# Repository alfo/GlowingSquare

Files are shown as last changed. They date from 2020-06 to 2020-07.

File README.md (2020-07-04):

# Glowing Square

This project is a purpose-built display based on a 64x32 LED matrix and an ESP32. The code can be easily adapted for other purposes, and includes code to fetch web requests, store config, etc.

I have made three displays so far: one that shows the current London Tube departures for my local station with data from TfL, one that shows planes flying over my house with data from Flightradar24 based on [this project](https://github.com/GroundBreakingItem0/esp8266_plane_tracker), and one that shows network statistics for my Unifi-based home network.



Full photo album [here](https://imgur.com/a/xTvUx8F).

## Features

* Fetches JSON data from an API at a given interval
* Parses the JSON and displays it
* Brightness controlled by MQTT
* "Party Mode" / Screensaver mode, turned on and off by MQTT
* WiFiManager-based hotspot for configuration

## Hardware Required
* 64x32 P4 LED Matrix (from [here](https://www.aliexpress.com/store/group/P4-led-module/1848738_509034839.html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))
* D1 Mini 32 (any of [these](https://www.aliexpress.com/wholesale?catId=0&initiative_id=SB_20200704011236&SearchText=mini+esp32))
* Optional: Brian Lough's Shield PCB (you can wire it yourself instead, but these are much neater) (from [here](https://www.tindie.com/products/brianlough/esp32-matrix-shield-mini-32/))
* 24V PSU (up to 35W per display) (I picked [this one](https://www.ebay.co.uk/itm/DC-5V-12V-24V-Universal-Regulated-Switching-Power-Supply-for-LED-Strip-CCTV-UK/162562112782) for 3 displays) 
* LM2596 Buck Converter to step down to 5V (from [here](https://www.aliexpress.com/wholesale?catId=0&initiative_id=SB_20200704011644&SearchText=LM2596))
* Two-core cable, Wago connectors/screw connectors, etc.
* 6x M3 12mm bolts, 16x 3mm short countersunk screws

You can just use a 5V power supply instead, but 100W+ ones tend to have loud fans in them, which is annoying, whereas my 24V 120W PSU is completely silent. It also helps with voltage drop if you're using long cables.

## Enclosure

See the files in the Enclosure folder for the STLs of the two 3D-printed parts of this project, as well as the full Fusion 360 model showing you how it all fits together and what wood is required for the project.

Back view

## Global Config Options

These options are available across all three displays:

* Hostname - what your device will show up in your router admin console as (can't contain spaces, etc)
* MQTT Server - the IP or domain name of your MQTT server
* MQTT Port - defaults to 1833
* MQTT Username
* MQTT Password

## MQTT Control

Set the room name (in the format `living_room` for example) in the web config interface, along with your MQTT server and port, etc. This will become the base of the topic when combined with the `MQTT_NAME` of your device in `mqtt.h`. Then the device will:

* Publish on `room_name/MQTT_NAME/mqtt` `connected` or `disconnected` as a last will and testament
* Listen on `room_name/MQTT_NAME/in` for messages in JSON format (e.g. `{ "brightness": 160 }` and will fade to the new brightness
* Listen on `room_name/state` for messages in JSON format (e.g. `{ "party_mode": "chill" }` (or `off` or `on`)

## Tube / London Bus

Find your TfL Stop ID [here](https://api.tfl.gov.uk/swagger/ui/index.html?url=/swagger/docs/v1#!/StopPoint/StopPoint_Search). TfL treats tube stops and bus stops the same, so if you provide the correct route and stop ID, it will work for both.

Config Options:

* TfL Stop ID
* TfL Route (e.g. `northern`, `circle`, `H91`, `9`), you can test your route [here](https://api.tfl.gov.uk/swagger/ui/index.html?url=/swagger/docs/v1#!/Line/Line_Arrivals)
* Direction (options are `outbound`, `inbound`, or empty for both)

## Flights

Use Google Maps or similar to find the longitude and latitude of the top left and bottom right points that define the area you want to monitor flights inside.

Config Options: 

* Flight Area in the format `51.5672,51.4131,-0.4146,0.1107` (for example)

## Unifi

Unlike the other two, this one requires a PHP script running on a web server (because Unifi needs 3 different API requests to fetch the info I wanted to display, and also Unifi returns JSON payloads that are too big to fit in the RAM of the ESP32).

Install the `GlowingSquare/Unifi/web/` files on your PHP server, and rename the `config.example.php` to `config.php`, filling in the necessary details as outlined by the code comments. Test that your server is working by visiting it in a web browser with `?width=64` appended to the URL to check you can scrape data correctly.

Config Options:

* Script URL as set up above, e.g. `http://10.0.1.9/glowingsquare/?width=64`

## Other Notes

This project was just started as a passtime during the 2020 COVID-19 lockdown as a bit of fun, happy to take questions but this isn't a long-term open source kinda deal, I'm just open-sourcing an already completed thing.

People have asked me if I'll be selling these, and I'll consider it and come up with a rough price estimate. It's a lot easier if you don't bother with the nice enclosure, which takes roughly 30% of the cost.

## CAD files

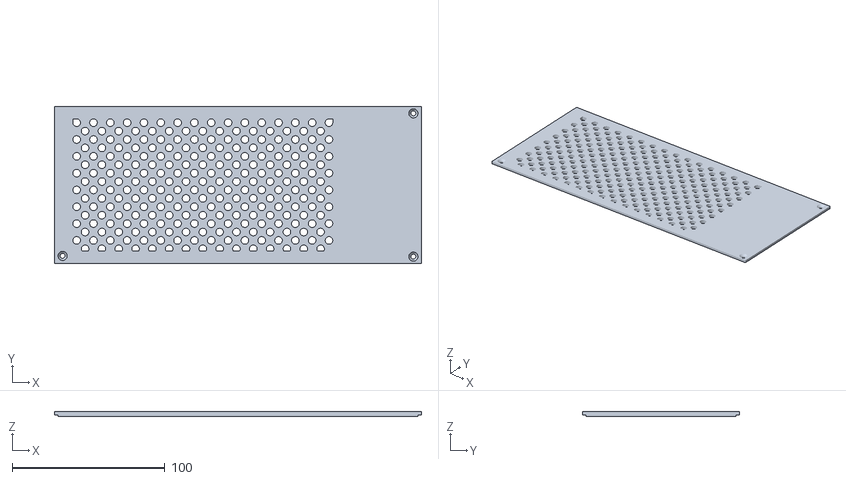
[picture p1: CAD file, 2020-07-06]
Enclosure/PSU Lid.stl
240.0 x 102.5 x 3.00

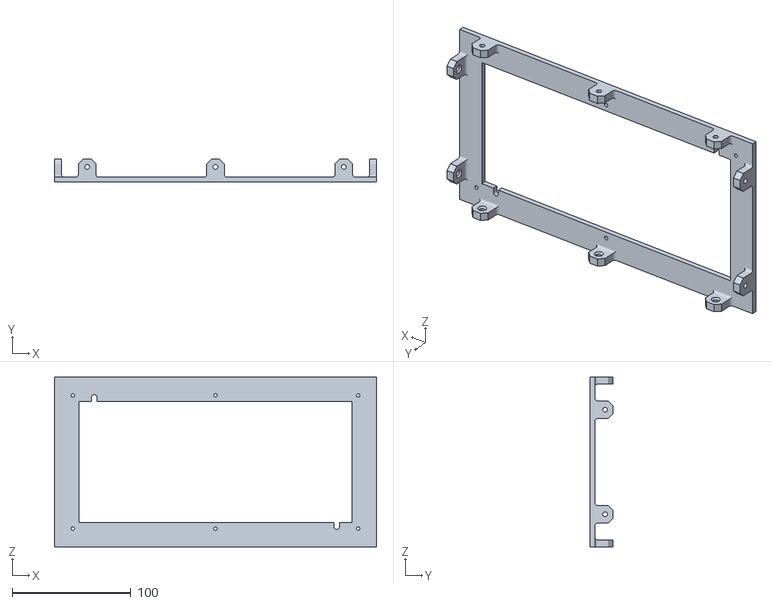
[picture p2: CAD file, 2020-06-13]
GlowingSquare_Tube/Enclosure/Display Mount.stl
271.0 x 19.0 x 143.0

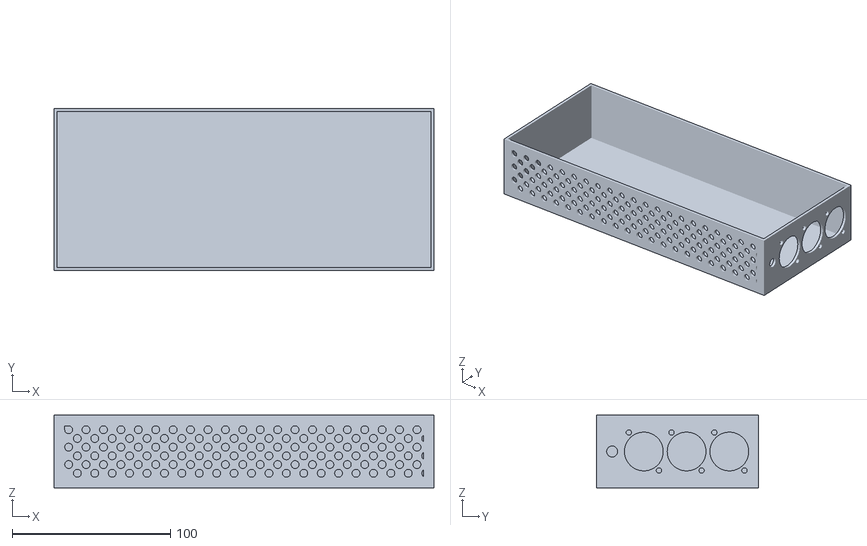
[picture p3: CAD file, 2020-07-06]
Enclosure/PSU Box.stl
240.0 x 102.5 x 46.0

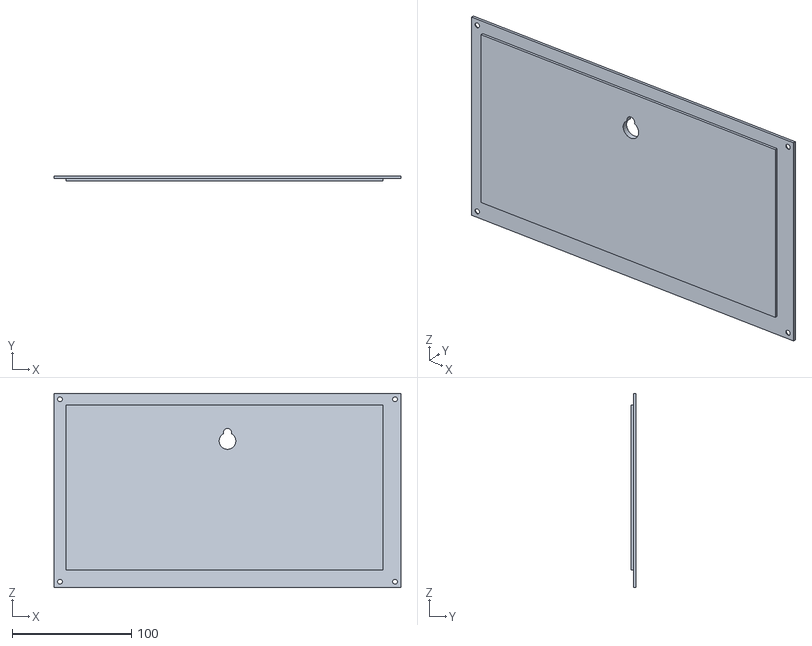
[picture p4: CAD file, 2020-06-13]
GlowingSquare_Tube/Enclosure/Wall Mount.stl
291.0 x 4.00 x 163.0

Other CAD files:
Enclosure/Wall Mount.stl
Enclosure/Glowing Square.f3d
GlowingSquare_Tube/Enclosure/Glowing Square.f3d

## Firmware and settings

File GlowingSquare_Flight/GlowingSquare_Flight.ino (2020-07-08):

/*
 *
 *
 *         _             ______
     /\   | |           |  ____|
    /  \  | | _____  __ | |__ ___  _ __ ___ _   _
   / /\ \ | |/ _ \ \/ / |  __/ _ \| '__/ _ \ | | |
  / ____ \| |  __/>  <  | | | (_) | | |  __/ |_| |
 /_/    \_\_|\___/_/\_\ |_|  \___/|_|  \___|\__, |
                                             __/ |
 Glowing Square: Flight Display             |___/
 For ESP32
 GlowingSquare_Flight.ino
 *
 */

// Include Libraries
#include <FS.h>            // this needs to be first, or it all crashes and burns...
#include <WiFiManager.h>   // https://github.com/tzapu/WiFiManager ~v2.0.0
#include <ArduinoJson.h>   // https://github.com/bblanchon/ArduinoJson ~v6.x.x
#include <PubSubClient.h>  // https://github.com/knolleary/pubsubclient ~v2.7.0
#include <ArduinoOTA.h>    // Included with core
#include <HTTPClient.h>    // To fetch data
                           // PxMatrix is included from inside the display.h file
#include <FastLED.h>       // For the animations during party mode

#ifdef ESP32
  #include <SPIFFS.h>
#endif

// Uncomment to reset device memory (useful to fix corruption / force new settings)
//#define START_ANEW

int party_mode = 0; // 0 = off, 1 = chill, 2 = party
int last_party_mode = party_mode;
uint8_t targetDisplayBrightness = 255;
uint8_t currentDisplayBrightness = 255;

#define INFO_UPDATE_INTERVAL 10000

// Include the other sketch files
#include "settings.h"
#include "display.h"
#include "wifi.h"
#include "flightradar.h"
#include "animations.h"
#include "mqtt.h"

void setup() {

  // Start serial
  Serial.begin(115200);
  Serial.println();

  // Load config from the file system
  setupStorage();

  // Start up WiFi and config parameters etc.
  startWiFiManagerWithParameters();

  // Must go after the SPIFFs stuff or we crash the ESP32
  setupDisplay();

  // Start ArduinoOTA service
  // So not just anyone can re-flash our devices
  ArduinoOTA.setPassword("chvFSEebm9X4GtpY");
  ArduinoOTA.begin();

  // Instantiate MQTT
  setupMQTT();

  setupAnimations();

}

// Variables just for the example code below
long lastWebRequest = -INFO_UPDATE_INTERVAL;

void loop() {

  // All-purpose way to keep track of the time
  long now = millis();

  // Loop our network services
  mqttLoop();          // Non-blocking MQTT connect/re-connect
  ArduinoOTA.handle();    // In case we want to upload a new sketch

  // Show tube stuff only if party mode is off
  if (party_mode == 0) {

    // We need to use the blocking fade because the
    // actual displaying of info is blocking too
    changeBrightnessBlocking(3000);

    // Only download new info every 10 seconds
    if (now - lastWebRequest > INFO_UPDATE_INTERVAL && currentDisplayBrightness != 0) {

      downloadFlightInfo();

      // Only display as offline if we've had 3 failed web requests in a row
      if (failed_attempts > 2) {
        displayOffline();
      } else {
        displayFlightInfo();
      }

      // Create a debug message
      lastWebRequest = now;

    }

  } else {

    // Use a non-blocking fade so the animation can continue
    // smoothly as we fade
    changeBrightnessNonBlocking();

    // Draw the next frame of our patterns
    patternLoop();

  }

}

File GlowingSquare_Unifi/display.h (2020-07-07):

/*
 *
 *
 *         _             ______
     /\   | |           |  ____|
    /  \  | | _____  __ | |__ ___  _ __ ___ _   _
   / /\ \ | |/ _ \ \/ / |  __/ _ \| '__/ _ \ | | |
  / ____ \| |  __/>  <  | | | (_) | | |  __/ |_| |
 /_/    \_\_|\___/_/\_\ |_|  \___/|_|  \___|\__, |
                                             __/ |
 Glowing Square: Unifi Display              |___/
 For ESP32
 display.h
 *
 */

// We will use PxMatrix in double-buffer mode to allow us
// to change many pixels and then update the display once in one go
#define double_buffer true

// Include must go here because double_buffer muse be defined first
#include <PxMatrix.h>

//
hw_timer_t * timer = NULL;
portMUX_TYPE timerMux = portMUX_INITIALIZER_UNLOCKED;

#define MATRIX_WIDTH 64
#define MATRIX_HEIGHT 32

// This defines the 'on' time of the display is us. The larger this number,
// the brighter the display. If too large the ESP will crash
#define DISPLAY_DRAW_TIME 70 // 30-70 is usually fine

// Create our display with the correct pins
// LAT=22, OE=2, A=19, B=23, C=18, D=5 (if there's an E it would be 15)
PxMATRIX display(MATRIX_WIDTH, MATRIX_HEIGHT, 22, 2, 19, 23, 18, 5);

// Some standard colors
uint16_t myRED     = display.color565(255, 0, 0);
uint16_t myGREEN   = display.color565(0, 255, 0);
uint16_t myBLUE    = display.color565(0, 0, 255);
uint16_t myWHITE   = display.color565(255, 255, 255);
uint16_t myYELLOW  = display.color565(255, 255, 0);
uint16_t myCYAN    = display.color565(0, 255, 255);
uint16_t myMAGENTA = display.color565(255, 0, 255);
uint16_t myBLACK   = display.color565(0, 0, 0);

// Display writer function from the example code
void IRAM_ATTR display_updater(){
  // Increment the counter and set the time of ISR
  portENTER_CRITICAL_ISR(&timerMux);
  display.display(DISPLAY_DRAW_TIME);
  portEXIT_CRITICAL_ISR(&timerMux);
}

// Draw a red pixel at the bottom of the display if we're
// offline, to show power is still on etc.
void displayOffline() {

  display.clearDisplay();
  display.drawPixel(MATRIX_WIDTH - 1, MATRIX_HEIGHT - 1, display.color565(255, 0, 0));
  display.showBuffer();
  display.copyBuffer();

}

// Function to clear all the pixels for a given row of text
// We have to do this otherwise the text always gets written over
// the previous text, instead of replacing it
void fillBlankRow(uint8_t ypos) {

  // Clear only the pixels on this part of the display
  for (int x = 0; x < MATRIX_WIDTH; x++) {
    for (int y = ypos; y < ypos + 8; y++) {
      display.drawPixel(x, y, display.color565(0, 0, 0 ));
    }
  }
}


void drawScrollingText(uint8_t ypos, int xpos, String scrollingText, uint8_t colorR_b, uint8_t colorG_b, uint8_t colorB_b) {
  // Write the scrolling text in its current position
  display.setTextColor(display.color565(colorR_b,colorG_b,colorB_b));
  display.setCursor(xpos, ypos);
  display.println(scrollingText);
}


void drawStaticText(uint8_t ypos, uint16_t offset, String staticText, uint8_t colorR_a, uint8_t colorG_a, uint8_t colorB_a) {

  // Write black over the area the static text will take up
  for (int x = 0; x < offset; x++) {
    for (int y = ypos; y < ypos + 8; y++) {
      display.drawPixel(x, y, 0);
    }
  }

  // Draw the static text
  display.setCursor(0, ypos);
  display.setTextColor(display.color565(colorR_a,colorG_a,colorB_a));
  display.println(staticText);

}

void drawRightAlignedText(uint8_t xpos, uint8_t ypos, String text) {

  uint8_t characterWidth = 5;
  uint16_t textLength = text.length();

  uint16_t offset = xpos - textLength * (characterWidth + 1);

  display.setCursor(offset, ypos);
  display.print(text);

}

void drawStaticAndScrollingText(uint8_t ypos, unsigned long scroll_delay, String staticText, String scrollingText, uint8_t colorR_a, uint8_t colorG_a, uint8_t colorB_a, uint8_t colorR_b, uint8_t colorG_b, uint8_t colorB_b) {

  // Asuming 5 pixel average character width
  uint8_t characterWidth = 5;

  uint16_t scrollingTextLength = scrollingText.length();
  uint16_t offset = staticText.length() * (characterWidth + 1);

  // Initial setup
  display.setTextSize(1);
  display.setRotation(0);

  // Each animation step of the scrolling
  for (int xpos = offset; xpos > -(MATRIX_WIDTH + scrollingTextLength * characterWidth) + 50; xpos--) {

    // Clear only the pixels on this part of the display
    fillBlankRow(ypos);

    drawScrollingText(ypos, xpos, scrollingText, colorR_b, colorG_b, colorB_b);

    drawStaticText(ypos, offset, staticText, colorR_a, colorG_a, colorB_a);

    // Draw the updates to the display
    display.showBuffer();

    // Copy the updates to the second buffer to avoid flashing
    display.copyBuffer();

    // Pause so we can set the speed of the animation
    delay(scroll_delay);
    yield();

  }

  // Write the scrolling text again, once the scroll has finished
  // so that it persists while we're scrolling the other lines
  fillBlankRow(ypos);
  drawScrollingText(ypos, offset, scrollingText, colorR_b, colorG_b, colorB_b);
  drawStaticText(ypos, 0, staticText, colorR_a, colorG_a, colorB_a);

  // Send the final line to the display
  display.showBuffer();
  display.copyBuffer();

}


void setupDisplay() {

  // Start up our display with a 1/16 scan rate
  display.begin(16);

  // This is required for my SRYLED P4 display to work properly
  display.setMuxDelay(0,2,0,0,0);

  // Empty anything in the display buffer
  display.flushDisplay();

  // We never want text to wrap in this project
  display.setTextWrap(false);

  display.setBrightness(currentDisplayBrightness);

  // More display setup bits taken from the double_buffer demo
  timer = timerBegin(0, 80, true);
  timerAttachInterrupt(timer, &display_updater, true);
  timerAlarmWrite(timer, 4000, true);
  timerAlarmEnable(timer);
}
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

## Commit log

2020-05-30 Commenting tubeapi code
2020-05-31 Fix bits and pieces
    [display.h]
2020-05-31 Added enclosure
    [Display Mount.stl, Glowing Square.f3d, Wall Mount.stl]
2020-06-01 My non-working Arduinojson code
    [Display Mount.stl, Glowing Square.f3d, Wall Mount.stl]
2020-06-08 Updated wall mount
    [Glowing Square.f3d, Wall Mount.stl]
2020-06-08 Add cut-out in display mount
    [Display Mount.stl, Glowing Square.f3d]
2020-06-09 Enlarged display border and added more tabs
    [Display Mount.stl, Glowing Square.f3d, Wall Mount.stl]
2020-06-13 Move tube into subfolder
    [Display Mount.stl, Glowing Square.f3d, Wall Mount.stl]
2020-06-13 Consolidated flights into own directory
    [Display Mount.stl, Glowing Square.f3d, Wall Mount.stl]
2020-06-13 Moved Enclosure files into root:
    [Display Mount.stl, Glowing Square.f3d, Wall Mount.stl]
2020-06-13 Added sample config
2020-06-13 Remove duplicates
    [Display Mount.stl, Glowing Square.f3d, Wall Mount.stl]
2020-06-13 Start Unifi arduino code
2020-06-15 Fixed so now we use the saved server URL
    [unifi.h]
2020-06-29 Update wall mount panel
    [Glowing Square.f3d, Wall Mount.stl]
2020-07-06 Add PSU box 3D parts
    [PSU Box.stl, PSU Lid.stl]
2020-07-07 Fix tube hanging bug and fade issue
    [GlowingSquare_Tube.ino, display.h]
2026-11-10 feat: Glowing Square 2, one firmware for every display
    The three 2020 sketches (Tube, Flight, Unifi) become one firmware built on
    esp32-iot-template. The display mode is chosen in the web interface, and
    each mode keeps its v1 layout.
    - Web interface: status with a live view of the matrix, settings for every
    option, network, firmware updates, logs.
    - WiFi from the web flasher (Improv) or a setup WiFi shown on the matrix.
    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
2026-11-10 chore: sync the template core to f2b63c1
    Brings the core changes that came with the template's touchscreen layer:
    the buildMainScreen(parent) hook signature, the setup-step screen id, the
    UI string table, and a check refusing raw hex colours outside the theme.
    The sync tool now leaves the UI-only core files (setup flow, screenshots)
    out of a headless project.
2026-11-10 fix: the repository is alfo/GlowingSquare
    GitHub Pages paths are case-sensitive: devices would have looked for
    version.json at /glowingsquare/ and found nothing.
2026-11-11 fix: boot loop on the D1 Mini 32 builds (v2.0.0-beta.2)
    Two crashes at start-up, both found on a real display:
    - The log ring (template core) came from IRAM on a classic ESP32 and the
    first log line panicked with a LoadStoreError.
    - PxMatrix refreshed from a hardware timer interrupt inside a critical
    section, as v1 did; on Arduino core 3 its SPI calls take a mutex there and
    FreeRTOS asserts. The 4 ms refresh now runs from an esp_timer task.
    Also brings the template's fix for a spurious WiFi error at first boot.
2026-11-11 feat: panel timing settings for the PxMatrix builds
    Settings > Panel sets the refresh period (v1: 4 ms) and each row's on-time
    (v1: 70 us), applied at once, for panels or power supplies that sing at the
    refresh rate. The log records how many refreshes ran.
    Tested on a real display: the panel lights, text scrolls smoothly, no
    whine at the defaults. README: flashing over USB needs the panel ribbon
    unplugged (OE is on the GPIO2 strapping pin).
2026-11-11 fix: steady panel refresh, and setup survives brownouts
    - PxMatrix refresh: the hardware timer interrupt (core 1, as v1) wakes a
    top-priority task on core 1 that does the SPI work. From the esp_timer
    task it ran on core 0 behind WiFi and the panel flickered while WiFi was
    busy.
    - Setup screen: each line holds still for 4 s, scrolls once and snaps
    back; a line that fits never moves, so the password can be read.
    - WiFi transmit power down to 15 dBm (APP_WIFI_TX_POWER): the radio's
    spikes sagged the shared 5V far enough to brown the board out.
    - Template core to 0bf66ae: a boot counts as failed only after a minute
    without an address, so brownout resets no longer reopen the setup por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
2026-11-11 chore: v2.0.0-beta.3
    Steady PxMatrix refresh (no flicker), a readable setup screen, lower WiFi
    transmit power, and brownouts no longer reopen setup. Confirmed on a D1
    Mini 32 display.
2026-11-11 fix: Tube with several lines and both directions; no heap leak
    - TfL answers an empty direction= with HTTP 400: both directions now send
    no direction at all, so circle,district at one stop works. Covered by the
    render test.
    - Changing a stop, line, area or console refetches at once.
    - Template core to 5249f7d: the daily update check leaked its TLS client
    (~55 kB per check, the task deleted itself before destructors ran), after
    which every HTTPS request on a D1 Mini 32 failed with connection refused.
    Tested on the display over WiFi (OTA upload): Notting Hill Gate,
    circle,district, both directions; heap back to ~139 kB after the update
    check; fetches succeed every minute.
2026-11-11 chore: v2.0.0-beta.4
    Fixes the update check's memory leak that stopped all HTTPS after a few
    minutes on the D1 Mini 32, and Tube with several lines in both directions.
2026-11-11 feat: Tube platform filter; steadier fetches; dark panel during updates
    - Tube: a Platform setting shows only departures from platforms whose name
    contains it ("Platform 1"). It picks one side of a station even when TfL
    gives a train no direction or the wrong line, as it does at Notting Hill
    Gate today. Covered by the render test.
    - Tube, Flights and routes read the whole answer before parsing. TfL's
    whole-stop list has no Content-Length and ends by closing; parsed off the
    TLS socket it sometimes lost its tail (JSON IncompleteInput).
    - The panel goes dark while firmware is written: flash writes stall the
    refresh and the panel strobed for the whole transfer.
2026-11-11 fix: the D1 Mini 32 displays stay up through WiFi start
    - The panel starts 2 s after the WiFi radio (or when the setup network
    opens), as v1 did, so the radio's start-up spike does not land on a
    refreshing panel.
    - Template core to 4403983 with APP_BROWNOUT_GUARD_MS = 6000: the brownout
    detector is off for the radio's first seconds. The Flight display reset on
    every boot without it.
    - The boot line says the panel is starting, not FAILED, before it starts.
    Tested on both displays: Tube up 25 min with steady heap; Flight up and
    fetching on PSU power (its endless brownouts came from USB and the PSU
    feeding the board together).
2026-11-11 fix: rows 7 and 15 no longer flicker on PxMatrix panels
    Settings > Panel gains a row switch settle time: a wait after each row
    address line, live. Rows 7 and 15 come right before all four address lines
    flip, and on the original displays they flickered with v1's settle time
    (0 us, B 2 us). 3 us steadied them; it is the new default.
    Tested on both D1 Mini 32 displays (Tube and Flight), installed over WiFi.
2026-11-11 chore: v2.0.0-beta.5
    Tube platform filter; fetches that survive TfL closing the connection; a
    dark panel during updates; WiFi credentials saved before the radio starts;
    the panel starting after the radio with a brownout guard; and a row settle
    time that steadies rows 7 and 15. Tested on two D1 Mini 32 displays.
2026-11-11 feat: Flights can take its centre from the browser's location
    A "Use my location" button on the Flights card asks the browser where it
    is, once, through a helper page on the project's GitHub Pages site. Also from
    the template: a save on the Settings page shows where you can see it, and the
    Firmware page fills in while Flights fetches over HTTPS.
2026-11-11 feat: the panel shows a progress line while firmware is written
    Instead of going dark for the whole update, the display shows one line
    that fills from left to right as the image arrives, and is full just
    before the restart. On the PxMatrix builds the refresh stops and the row
    is held lit by the LEDC peripheral, so the stalls of flash writes cannot
    make it strobe. A failed update brings the mode's own picture back.
2026-11-11 fix: Flights keeps working when adsb.lol is down, and over a busy sky
    adsb.lol stopped answering on 11.11.2026, its website too, and the
    display showed nothing. Flights now asks adsb.fi when adsb.lol fails,
    and keeps asking the feed that answered last.
    The answer is now read one aircraft at a time instead of whole: 50 nm
    around London is 55 kB, more than the board could hold, and the
    display showed nothing at that radius either.
2026-11-11 fix: Tube shows the right trains at Notting Hill Gate, and fetches reliably
    TfL names every train on Notting Hill Gate's platform 1 wrongly: the
    Circle via Victoria comes as the Hammersmith & City to "Hammersmith",
    and the District to Wimbledon as "Check Front of Train". A new Rename
    setting (Settings > Tube) turns a destination into what the platform's
    own sign says, e.g. "Hammersmith=Circle via Victoria; Check Front of
    Train=Wimbledon".
    TfL's answer for the whole stop (27 kB) also often arrived cut off
    ("JSON: IncompleteInput"), so the display showed nothing. Tube and
    Flights now read an answer whole into small blocks, as fast as it
    arrives, and then parse it a train or an aircraft at a t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
2026-11-11 fix: a panel whose refresh stops comes back by itself
    The Flight display's panel went black with the picture still drawn
    behind it: the PxMatrix refresh timer had stopped, and restarting it
    brought the panel back. The display now watches its refresh. When it
    stands still outside an update, the refresh is started again and that
    is logged; if that does not help, the display restarts. The Status
    data has the refresh count, so a black panel whose count still moves
    points at the panel or its wiring instead.
2026-11-12 fix: settings rows line up, with the same spacing and rules throughout
    From esp32-iot-template c84c3a5: every field starts at the same place,
    the help button sits beside the setting's name, and every row has a rule
    below it.
2026-11-12 fix: Flights shows aircraft again now adsb.lol refuses HTTP/1.0
    adsb.lol answers HTTP/1.0 requests with 426 Upgrade Required. Any HTTP
    status counted as an answer, so Flights showed a clear sky and never asked
    adsb.fi. An error status now fails the feed, Tube and UniFi included, and
    adsb.lol is asked over HTTP/1.1.
2026-11-12 feat: Flights shows the airline's logo, in a calmer colour scheme
    The nearest flight now has its airline's mark top left, drawn on black at
    16x16, from a curated list of about 55 airlines over London and Heathrow's
    regulars (tools/gen_airline_logos.py). Any other aircraft shows a plain
    plane. An arrow says whether it is climbing, descending or level, the
    altitude reads 2,475ft, and each line has its own colour.
2026-11-12 fix: Flights shows each new flight on the panel, not only in the live view
    A fetched answer was drawn but never pushed to the panel. Tube scrolls,
    which pushed it soon after; Flights draws once, so its panel stayed dark
    or on an old flight until something else redrew it.
2026-11-12 fix: Unifi reads a network's whole client list, however many clients
    Each answer is walked straight off the socket, an element at a time, so
    only a 512-byte buffer and one client are held: parsed at ArduinoJson's
    pace it arrived cut off. A report with no figures in it now says so in
    the log, and the log is written from the loop, not the fetch task.
2026-11-12 fix: Unifi's graph and month totals come back, built from live WAN rates
    A UniFi Network update in November 2026 left the report endpoints empty,
    for v1's script too. The display now samples the WAN's rates from
    stat/health on every fetch: the graph fills in over 64 x 5 minutes from
    power-on, and the month's totals are kept on the device, saved every 15
    minutes.
2026-11-12 fix: Unifi's graph is full again from the start, from the console's dashboard
    The graph and the month's totals come from the Network app's own dashboard
    (v2 aggregated-dashboard, wan_activity alone): the last 100 x 5 minutes of
    download rate for the graph, every 5 minutes, and the month's rates times
    their hours for the totals, every 30 minutes. Nothing is kept on the
    device, and the history is there from the first fetch.
